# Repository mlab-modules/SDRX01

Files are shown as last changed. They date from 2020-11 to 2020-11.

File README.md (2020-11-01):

<!--- module --->
# SDRX01B - SDR Receiver
<!--- Emodule --->

<!--- subtitle --->
A improved design of well known DR2G software defined receiver. It is capable to work from almost zero frequencies up to 200MHz but up to 450MHz with selected parts.
<!--- Esubtitle --->

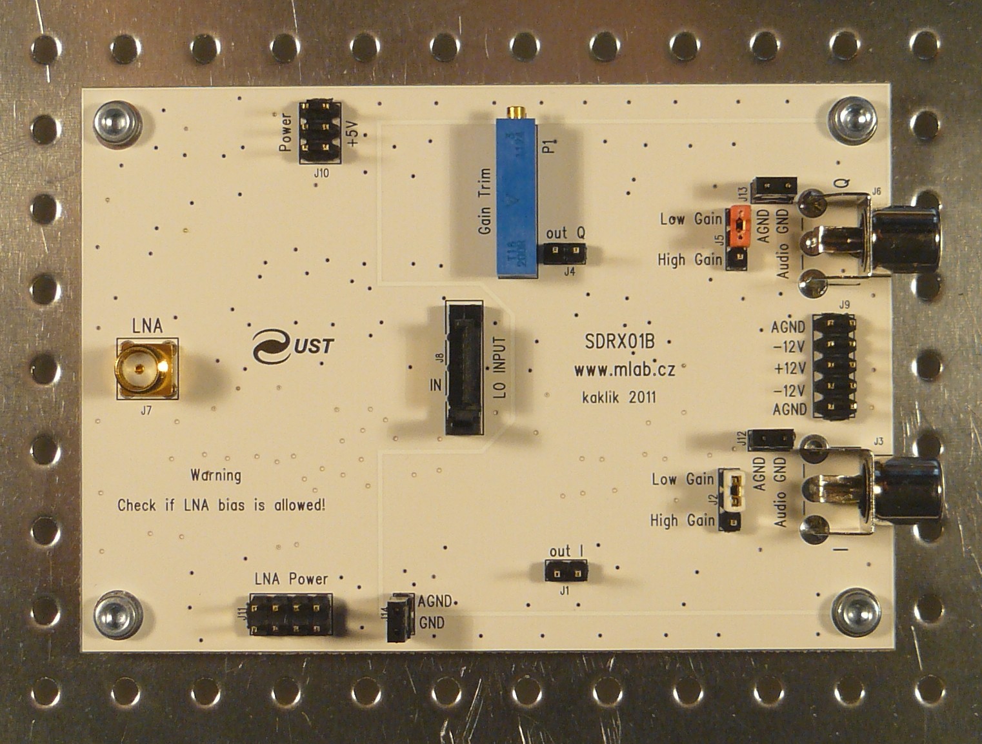
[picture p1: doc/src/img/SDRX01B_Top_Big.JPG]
SDRX01B Top


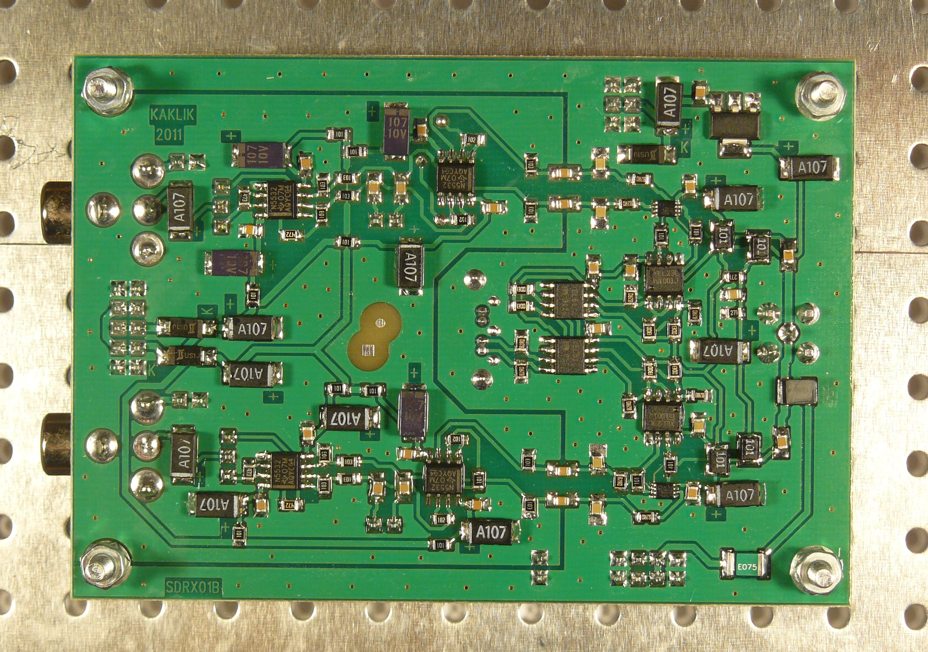
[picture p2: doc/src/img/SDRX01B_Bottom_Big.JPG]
SDRX01B Bottom


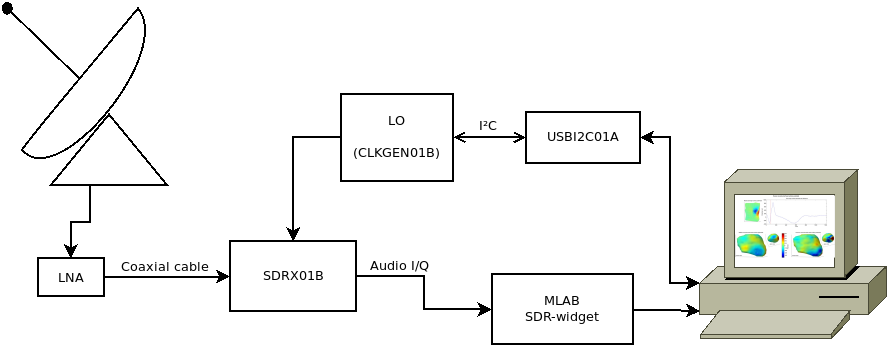
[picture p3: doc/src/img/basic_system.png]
SDRX01B Basic usage


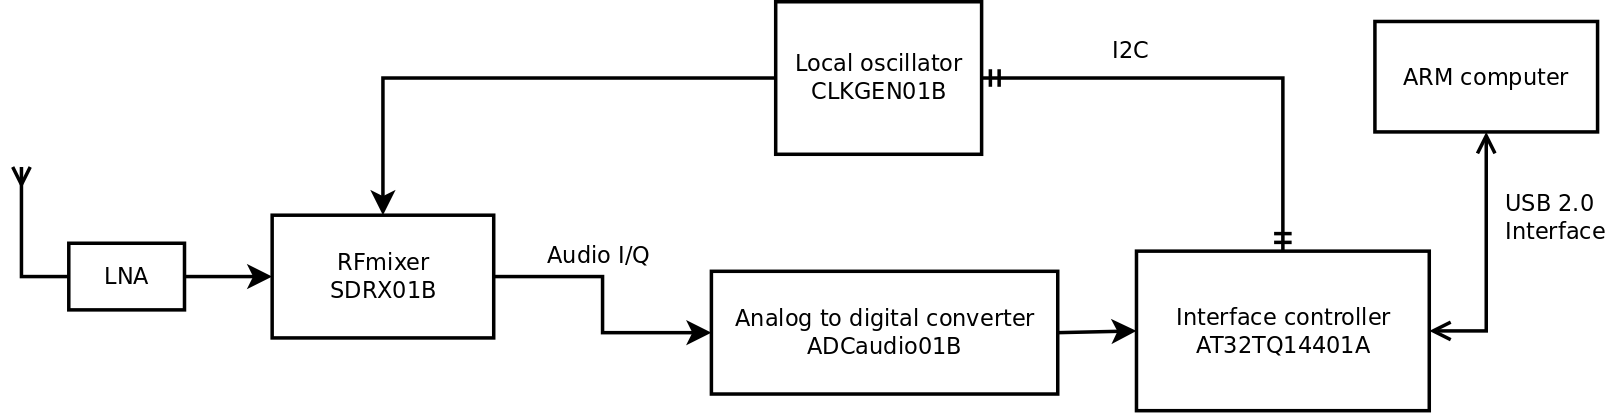
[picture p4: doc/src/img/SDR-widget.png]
Sdr-widget


<!--- description --->

<!--- Edescription --->

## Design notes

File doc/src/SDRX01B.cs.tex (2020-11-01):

\documentclass[12pt,a4paper,oneside]{article}
\usepackage[colorlinks=true,unicode]{hyperref}
\usepackage[utf8]{inputenc}
\usepackage[czech]{babel}
\usepackage{graphicx}
\usepackage{pdfpages}
\textwidth 16cm \textheight 25cm
\topmargin -1.3cm 
\oddsidemargin 0cm
\usepackage{footnote}
\pagestyle{empty}
\begin{document}
\title{Softwarově definovaný přijímač SDRX01B nejen pro radioastronomii}
\author{Jakub Kákona, kaklik@mlab.cz }
\maketitle

\begin{abstract}
Cílem této konstrukce je vytvořit dostupný softwarově definovaný přijímač pro použití v radioastronomii. A nahradit tak původní čistě analogové konstrukce, jako RadioJOVE a další. Díky dosaženým parametrům je ale dobře použitelný i v jiných aplikacích, jako například přehledový přijímač pro radioamatéry nebo jako studijní pomůcka pro výuku VF techniky. 
\end{abstract}

\begin{figure} [htbp]
\begin{center}
\includegraphics [width=80mm] {./img/SDRX01B_Top_Big.JPG} 
\end{center}
\end{figure}

\begin{figure} [b]
\includegraphics [width=25mm] {./img/SDRX01B_QRcode.png} 
\end{figure}

\newpage
\tableofcontents

\section{Technické parametry}
\begin{savenotes}
\begin{table}[htbp]
\begin{center}
\begin{tabular}{|c|c|p{5cm}|}
\hline
Parametr & Hodnota & \multicolumn{1}{|c|}{Poznámka} \\
\hline
Napájecí napětí analogové části & $\pm$12V \footnote{první kusy vyrobené do 1.8.2011 ale mohou mít osazené pouze 10V konenzátory 100uF} 100mA &  Typicky 30mA \\ \hline
Napájecí napětí digitální části & +5V &  300mA \\ \hline
Napájecí napětí LNA & do +20V &  max 500mA \\ \hline
Přijímaný frekvenční rozsah  & 0,5 - 200 MHz\footnote{Prakticky je omezen kvalitou vstupních spínačů směšovače} &  \\ \hline
Vstupní frekvenční rozsah LO  & 1 - 400 MHz \footnote{Digitální část je dimenzována do cca 1 GHz} & Limitem je LO  \\ \hline
IIP3  & $>$ 0 dB & Hodnota závisí na parametrech zvukové karty \\ \hline
MDS  & -120 dBm @ 1kHz BW & -117 dBm pro 3 dB nad šumem  \\ \hline
Potlačení zrcadlového příjmu   & $>$ 50 dB & Typicky 70dB \footnote{Hodnota závisí na přesnosti nastavení P1}\\ \hline
Zisk & 40-60dB & Lze částečně ovlivnit konfigurací NF zesílení\\ \hline
Šumové číslo  & $<$ 30dB & \\ \hline
\end{tabular}
\caption{Údaje uvedené v tabulce jsou platné pro příjem na frekvenci 150MHz.}
\label{Technicke_parametry}
\end{center}
\end{table}
\end{savenotes}

\newpage
\section{Popis konstrukce}

\subsection{Zapojení}
Zapojení přijímače vychází z původní konstrukce SDR přijímače DR2G \cite{DR2G}  který požívá CMOS součástky. Nyní je u přijímače změněný hlavně obvod vstupu pro lokální oscilátor a umožňuje tak používat přijímač na vyšších kmitočtech, neboť nedělí vstupní frekvenci 4mi, jako původní konstrukce ale pouze 2mi. To mimo jiné znamená, že nejvyšší pracovní kmitočet již není limitován vstupní logikou, ale analogovými spínači a v menší míře i převodníky LVPECL-CMOS těsně před spínači. Použitá diferenciální LVPECL logika navíc také umožňuje podstatně snížit vyzařování. Dále byly vyměněny analogové spínače ve směšovači. Ty nyní spínají trochu rychleji, ale hlavně mají lepší izolační parametry, což umožňuje lepší odstup signálu od šumu.

\includepdf[pages={1,2,3,4},landscape=true]{../../SCH/sdrx.pdf}

Další nezbytnou součástí přijímače je lokální oscilátor, který se připojuje k přijímači externě pomocí krátkého SATA kabelu. Jako LO lze použít modul CLKGEN01B osazený 570ABB000107DG. SATA kabel je vhodné volit co nejkratší kvůli minimalizaci zemní smyčky a vyzařování.

\subsection{Odrušení}
Pro správnou funkci přijímače je nutné řádné odrušení napájecích zdrojů. Vhodné je také omezit zemní smyčky a zem rozvádět pokud možno hvězdicově. Konstrukce obsahuje několik Jumperů, kterými je možné různými způsoby propojit země a eliminovat tak proudy tekoucí mezi nimi. Zvláště nežádoucí je proměnný proud tekoucí stíněním, například u výstupních CINCHů, Jumpery proto umožňují jejich odpojení od AGND přijímače. V tom případě se ale předpokládá propojení země ADC a AGND externím vedením, tak aby jím tekoucí proud neindukoval signál v analogových obvodech.
V některých případech (anténa uzemněna na hromosvod, nebo daleko od přijímače) se může vyskytnout problém se síťovým napájeným 50Hz indukovaným do svodu antény. Ten pak vytváří okolo nulové frekvence spektrogramu nežádoucí hrb, ten lze pak v takovém případě eliminovat oddělovacím transformátorem, na vstupu přijímače.     

Při provozu je také vhodné zabezpečit dostatečný útlum zpětně vyzařovaného útlumu ze směšovače, který by mohl rušit jiná zařízení a spoje. Na vstupu přijímače proto musí být zařazen izolační prvek, jako například LNA. 

\subsection{Mechanická konstrukce}

Mechanická konstrukce je řešena na dvouvrstvé desce s geometrií kompatibilní se základo\-vou deskou MLAB (Pro lepší odstínění přijímače je vhodné použít duralovou desku ALBASE). Dvouvrstvý plošný spoj je zvolen hlavně kvůli kvalitnímu odstínění okolního rušení horní měděnou vrstvou. To umožňuje přijímače instalovat i velmi blízko sebe případně i nad sebe avšak všechny konektory  kromě NF audio výstupu předpokládají přivedení kabelu kolmo na rovinu desky. SMA konektor je možné osadit i úhlový s přivede\-ním kabelu do boku, ale za cenu nepatrně vyššího útlumu úhlového konektoru. Při těsné montáži je potřeba počítat i s určitou teplotní stabilizací, neboť digitální část okolo spínaného směšovače má poměrně velký příkon a způsobuje zahřívání zhruba o 15$^\circ C$ nad okolní teplotu. Pokud je od přijímače vyžadována dlouhodobá stabilita je proto vhodné jej umístit do termostatovaného boxu společně s LO.

\section{Výroba}
Výrobu vlastní desky pro přijímač nemohu doporučit. Neboť domácí výroba je dvouvrstvého plošného spoje je náročná sama o sobě a tento motiv plošného spoje navíc obsahuje plošky pro komponenty s poměrně vysokou třídou přesnosti.

\subsection{Osazení}
Vlastní osazení přijímače předpokládá zvládnutí SMT technologie. Nejkomplikovanější část je letování analogových spínačů u kterých je nutné dát pozor na přehřátí a je tedy vhodné použít více tavidla. Následně je potřeba pod mikroskopem zkontrolovat kvalitu pájení (zkraty, nepřipojené nožičky).

\begin{figure} [h!tbp]
  \centering
  
  
  \caption{Osazovací plán horní a spodní strany plošného spoje}
  \label{fig:osazovaci_plan}
\end{figure}

\begin{table}[h!]
\begin{center}
\begin{tabular}{ |c|p{5cm}|c|c| }
\hline 
Počet & Označení & Typ  & Pouzdro  \\ 
\hline 
18	&	C1, C4, C8, C10, C12, C15, C19, C21, C23, C27, C30, C32, C36, C39, C40, C41, C42, C45	&	100nF	&	805	\\
17	&	C2, C5, C9, C11, C13, C16, C20, C22, C24, C31, C35, C43, C44, C46, C47, C48, C49	&	47uF	&	SMC	\\
4	&	C3, C6, C14, C17	&	4,7uF	&	805	\\
4	&	C25, C28, C33, C37	&	470nF	&	805	\\
4	&	C26, C29, C34, C38	&	22nF	&	805	\\
3	&	D1, D2, D3	&	M4	&	SMA	\\
1	&	F1	&	750mA	&		\\
5	&	J1, J4, J12, J13, J14	&	JUMP2	&		\\
2	&	J2,J5	&	JUMP3	&		\\
1	&	J3	&	CINCH I	&		\\
1	&	J6	&	CINCH Q	&		\\
1	&	J7	&	SMA6251A13G50	&		\\
1	&	J8	&	JUMP7	&		\\
1	&	J9	&	JUMP2X5	&		\\
1	&	J10	&	JUMP2X3	&		\\
1	&	J11	&	JUMP2X4	&		\\
5	&	L1, L2, L3, L4, L5	&	100uH	&		\\
1	&	P1	&	200	&	805	\\
13	&	R1, R2, R8, R14, R15, R16, R17, R28, R30, R32, R34, R36, R40	&	100	&	805	\\
12	&	R3, R5, R7, R9, R12, R13, R18, R19, R23, R24, R27, R29	&	10k 1\%	&	805	\\
4	&	R4,R11,R21,R26	&	1k 1\%	&	805	\\
2	&	R6,R22	&	47k 1\%	&	805	\\
2	&	R10,R25	&	4k7 1\%	&	805	\\
10	&	R31, R33, R35, R39, R45, R46, R47, R48, R51, R52	&	82	&	805	\\
2	&	R37,R38	&	330	&	805	\\
6	&	R41,R42,R43,R44,R49,R50	&	130	&	805	\\
2	&	U1,U3	&	LT6231	&	SO8	\\
2	&	U2,U4	&	NE5532	&	SO8	\\
2	&	U5,U6	&	NC7WB66	&		\\
2	&	U7,U9	&	MC100EP51	&	SO8	\\
2	&	U8,U10	&	SY100ELT23	&	SO8	\\
1	&	U11	&	LM1117MPX	&	SOT	\\
\hline 
\end{tabular}
\end{center}
\caption{Seznam součástek plošného spoje.}
\label{seznam_soucastek}
\end{table}

\subsection{Testování}
Testování přijímače spočívá v připojení na zdroje napájecího napětí s omezením proudu nastaveným na maximální hodnoty uvedené v tabulce \ref{Technicke_parametry}. Symetrický napájecí zdroj musí být dostatečně kvalitní a vyhlazený, aby nedocházelo k průniku rušení do analogové části. Je taktéž vhodné aby i symetrický zdroj měl proudové omezení. Pokud proudový odběr nepřekračuje stanovené limity. Můžeme připojit i lokální oscilátor. Pro testovací účely stačí použít modul CLKGEN01B pouze s připojeným napájením, tím dosáhneme přivedení jeho základní frekvence 10 MHz na vstupní děličku přijímače.  

Nyní můžeme osciloskopem zkontrolovat signál na vstupu analogových spínačů, kde by po připojení oscilátoru přes SATA kabel měl být měřitelný TTL signál. Se střídou 50 \% a frekvencí 5 MHz. Je potřeba změřit každý vstup spínače samostatně.  Pokud jsou analogové spínače v pořádku, lze pokračovat v ověření parametrů analogové části. To provedeme změřením napěťového offsetu na výstupním operačním zesilovači. Jeho hodnota by neměla být více než 1 V, měření je vhodné provádět osciloskopem, neboť tím lze detekovat i případné kmitání operačních zesilovačů. 

\subsection{Nastavení}

Následně je důležité nastavení shodných amplitud obou výstupních kanálů I a Q na stejnou hodnotu pomocí víceotáčkového trimru na horní straně desky. To lze udělat buď pomocí zvukové karty a minimalizace zrcadlových kmitočtů nějakého relativně silného AM vysílače. Nebo lze použít i metodu, kdy pomocí Jumperů, které slouží na výběr zesílení odpojíme jeden kanál (ten ve větvi s trimrem) a v softwaru si označíme aktuální úroveň signálu z antény. Pak analogicky kanál odpojíme připojíme naopak původně odpojený. Pomocí trimru pak nastavíme stejnou hodnotu signálu. Tento způsob je velmi jednoduchý a lze ho použít i za chodu, ale není příliš přesný. hodí se spíše na detekci poruchy (nefungující jeden z kanálů). 

Nejpřesnější metoda je použití signálového generátoru, který necháme vysílat do přijí\-ma\-če signálem cca -50dBm na požadovaném kmitočtu, kde potřebujeme přijímač zkalibrovat a trimrem nastavíme zrcadlový kmitočet ve spektrogramu na minimální hodnotu. Pokud nemáme signálový generátor lze využít například další přijímač SDRX01B s dalším lokálním oscilátorem. Který díky zpětnému vyzařování do antény umožní stejný postup.
Další jeměšjí potlačení zrcadlového kmitočtu lze provádět vhodným nastavením zesílení jednotlivých kanálů ADC a jejich fázovým posuvem. Většina programů pro SDR má proto možnost vyvážení amplitudy a fáze.  

\section{Programové vybavení}

Základním programovým vybavením jsou všechny softwary využívající zvukovou kartu v komplexním režimu (I/Q) pro vstup signálu. Tedy například programy jako Winrad, WinradHD, HDSDR či Spectrum Lab. Do kterých většinou stačí přidat knihovnu pro ovládání LO s Si570, nebo lokální oscilátor ovládat jiným softwarem.

\section{Důležité poznámky k používání}
\begin{itemize}
\item Vzhledem k použitému principu spínaného směšovače přijímač z principu poměrně silně vyzařuje zpět do antény. \textbf{Nesmí se proto využívat k poslechu chráněných pásem přímo bez izolačního členu na vstupu!} (izolačním členem je myšlen prvek, který zabezpečí dostatečný útlum signálu směřujícího do antény, obvykle jde o LNA, nebo izolační zesilovač)

\item Aktuální způsoby použití a poznatky uživatelů přijímače najdete na wiki stránce MLAB \cite{SDRX}.
\end{itemize}

\begin{thebibliography}{99}
\bibitem{DR2G}{Původní konstrukce přijímače DR2G} 
\href{http://yu1lm.qrpradio.com/SMT SDR RX DR2G-YU1LM.pdf}{http://yu1lm.qrpradio.com/SMT SDR RX DR2G-YU1LM.pdf}
\bibitem{SDRX}{MLAB wiki stránka přijímače SDRX01B} 
\href{http://wiki.mlab.cz/doku.php?id=cs:sdrx}{http://wiki.mlab.cz/doku.php?id=cs:sdrx}
\end{thebibliography}
\end{document}

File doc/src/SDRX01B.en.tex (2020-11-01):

\documentclass[12pt,a4paper,oneside]{article}
\usepackage[colorlinks=true]{hyperref}
\usepackage[utf8]{inputenc}
\usepackage[english]{babel}
\usepackage{graphicx}
\usepackage{pdfpages}
\textwidth 16cm \textheight 25cm
\topmargin -1.3cm 
\oddsidemargin 0cm
\usepackage{footnote}
\pagestyle{empty}
\begin{document}
\title{Software Defined Receiver SDRX01B not only for radioastronomy}
\author{Jakub Kákona, kaklik@mlab.cz }
\maketitle

\begin{abstract}
This paper describe a design of Software Defined Receiver suitable for radioastronomy purposes. The receiver which has been developed in this project replacing old analog constructions such as RadioJOVE and others.
\end{abstract}

\begin{figure} [htbp]
\begin{center}
\includegraphics [width=80mm] {./img/SDRX01B_Top_Big.JPG} 
\end{center}
\end{figure}

\begin{figure} [b]
\includegraphics [width=25mm] {./img/SDRX01B_QRcode.png} 
\end{figure}

\newpage
\tableofcontents

\section{Technical parameters}
\begin{savenotes}
\begin{table}[htbp]
\begin{center}
\begin{tabular}{|c|c|p{5cm}|}
\hline
\multicolumn{1}{|c|}{Parameter} & \multicolumn{1}{|c|}{Value} & \multicolumn{1}{|c|}{Note} \\ \hline
Power voltage for analog circuits & $\pm$12 V 100mA \footnote{First devices manufactured before 1.8.2011 may be equipped by 10 V tatal capacitors onl thus cannot by longly stressed by $\pm$12 V power voltage } &  Typical current draw 30 mA \\ \hline
Powering voltage for digital part & +5V &  300mA \\ \hline
Bias of optional LNA & up to +20V max 500mA &   Fused by 750mA on board \\ \hline
Frequency range  & 0,5 - 200 MHz & With populating by chosen parts even up 450MHz \\ \hline
IIP3  & $>$ 0dB & Preliminary \\ \hline
Gain & 40-60dB & Selectable by jumper \\ \hline
Self noise number & $<$ 30dB & \\ \hline
\end{tabular}
\end{center}
\end{table}
\end{savenotes}

\newpage
\section{Description of construction}

\subsection{Circuit}
Construction  of the receiver is delivered from the DR2G receiver \cite{DR2G} which uses CMOS components completely. The main change in this construction is a local oscillator input circuit which allow to receiver work at higher frequencies, because this construction do not divide the input frequency by 4, such as original construction but only by 2. In addition there was be replaced switches in the sampling mixer by faster type and board layout was optimized for higher frequencies and better noise rejection.

\includepdf[pages={1,2,3,4},landscape=true]{../../SCH/sdrx.pdf}

The necessary part of the receiver is a Local Oscillator (LO), which must be connected to receiver via SATA cable. The LO may be a CLKGEN01B module populated by the 570ABB000107DG chip. SATA cable should be as short as possible to minimize ground loops.

\includepdf[pages={1},landscape=true]{../../CAM_DOC/O1.pdf}

\includepdf[pages={1},landscape=true]{../../CAM_DOC/O2.pdf}

\subsection{EMI suppression}
For proper function of receiver is necessary to use proper low noise symmetric power supply (classical PC power supply is unacceptable). There is need for proper routing of grounding wires, which must be routed in star topology. In addition there is few jumpers on the board of receiver to allow proper selection of ground connection.

\subsection{Mechanical construction}

The mechanical construction of the receiver resulted (For better EMI suppression is suggested use of metal MLAB base such as ALBASE). Two layer PCB is chosen mainly because of better shielding by top cooper layer and even because better grounding. In case where long term stability is required receiver must be inserted to thermostatic box together with LO. 

\subsubsection{Setting}
There is one easy step for proper setting of the receiver. The trimmer P1 must be tunned to value where the strength of mirror frequencies is minimized or zero. This can be achieved by tunning the receiver to some strength AM transmitter and slowly turning by P1 until the mirror of signal in frequency spectrum is minimized. 

\section{Software tools}

The basic software tools for this receiver are all programs designed to work with sound card as I/Q input. Such as Winrad, WinradHD or Spectrum Lab. There is usually request to add a LO library for tunning Si570, but tunning the LO by separate software is acceptable too.

\begin{thebibliography}{99}
\bibitem{DR2G}{The original construction of DR2G} 
\href{http://yu1lm.qrpradio.com/SMT SDR RX DR2G-YU1LM.pdf}{http://yu1lm.qrpradio.com/SMT SDR RX DR2G-YU1LM.pdf}

\end{thebibliography}
\end{document}

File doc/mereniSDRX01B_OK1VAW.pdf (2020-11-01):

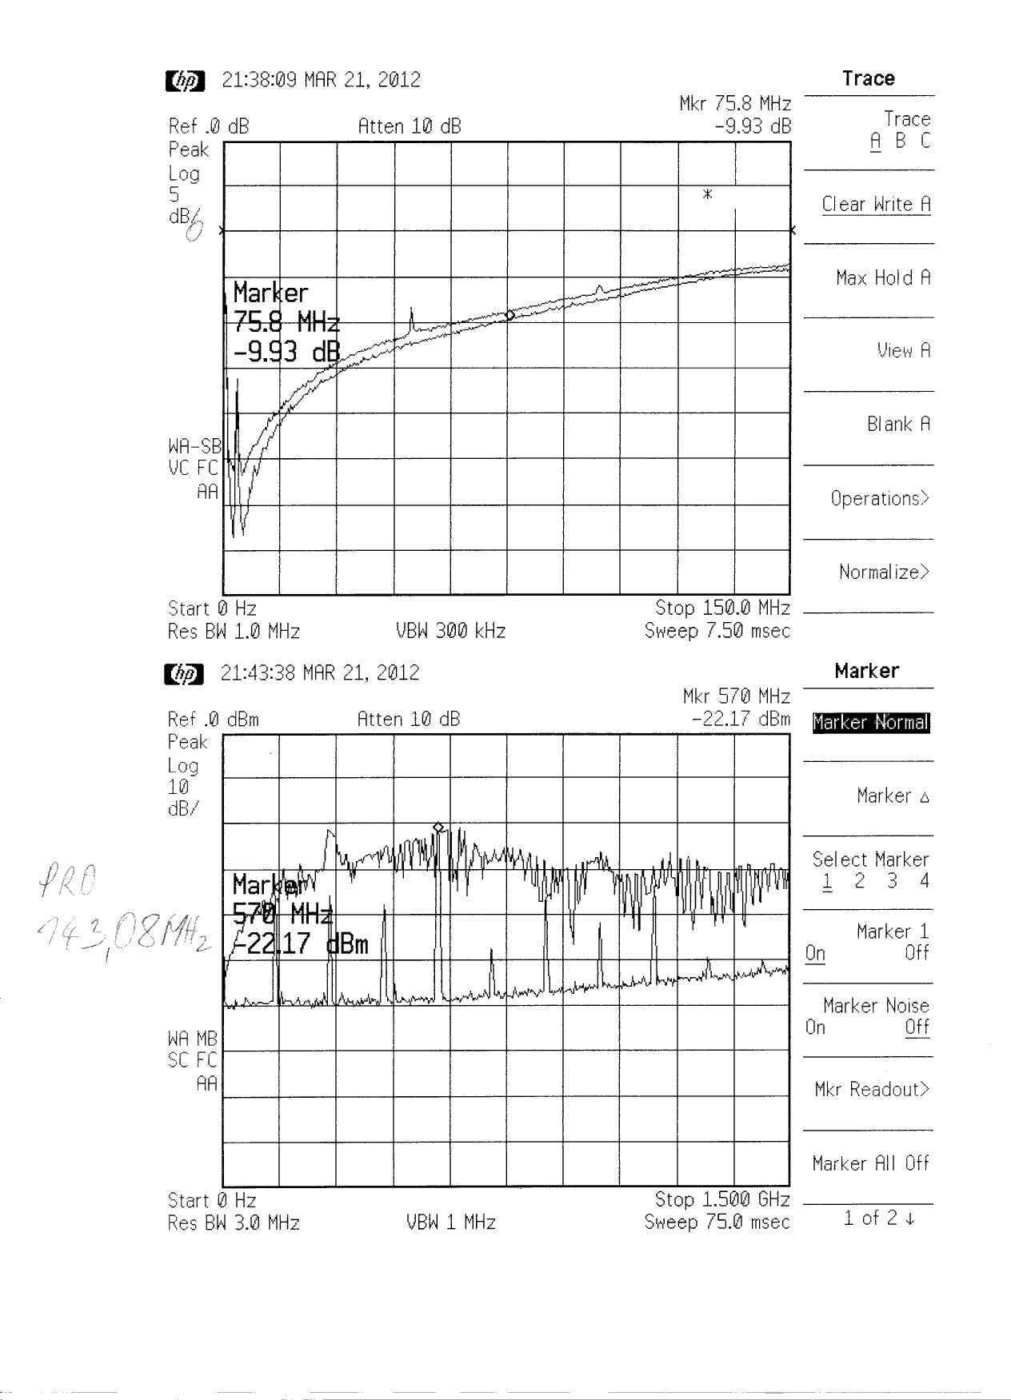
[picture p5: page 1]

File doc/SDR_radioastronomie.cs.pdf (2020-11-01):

## SDR Radiostronomie

Možnost astronomického
pozorování pro den i noc
nezávisle na počasí i uprostřed města.

## Základní pozorovatelné objekty

- Ionosféra
- Sluneční bouře
- Meteory
- Magnetické bouře Jupiteru
- Galaktický šum

## Potřebné vybavení

Anténa, zesilovač, přijímač, zvuková karta a počítač.

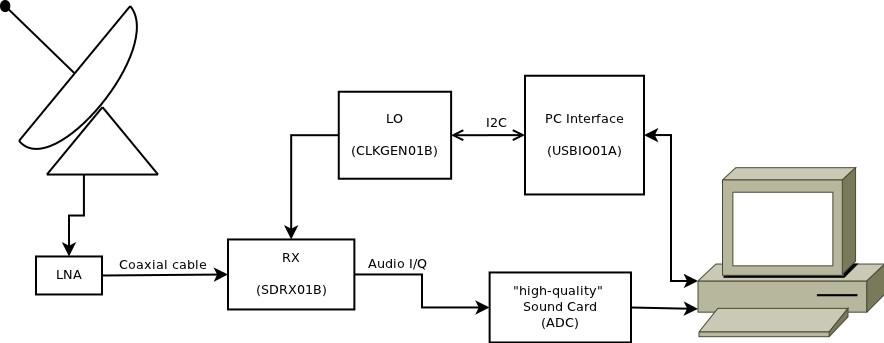
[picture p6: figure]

## Příklad - Detekce meteorů

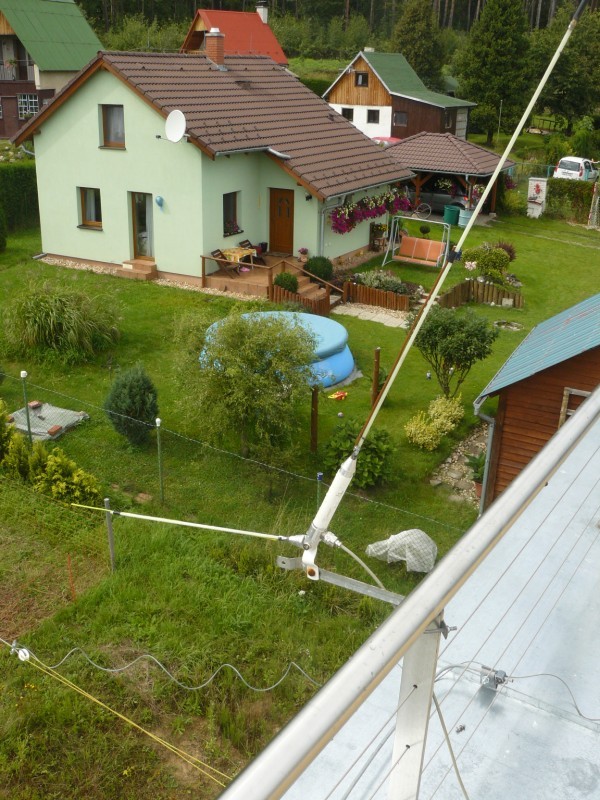
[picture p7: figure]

„balkónová anténa“
- ¼ λ Vertical (Ground
Plane)
- Předzesilovač
LNA01A
- Přijímač SDRX01B

## Pozorovací pracoviště

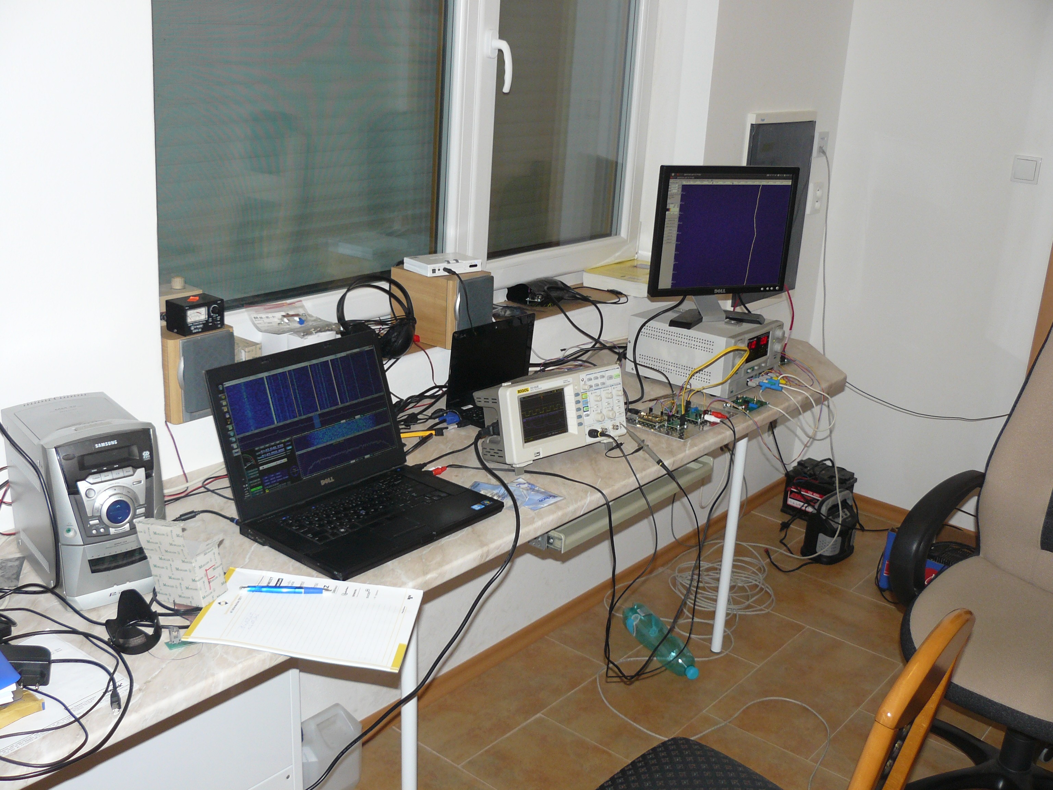
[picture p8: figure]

## Výsledky (Drakonidy)

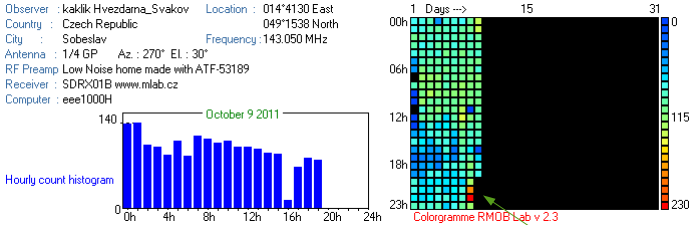
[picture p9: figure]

Detekováno krátké maximum

## Spektrogramy z maxima

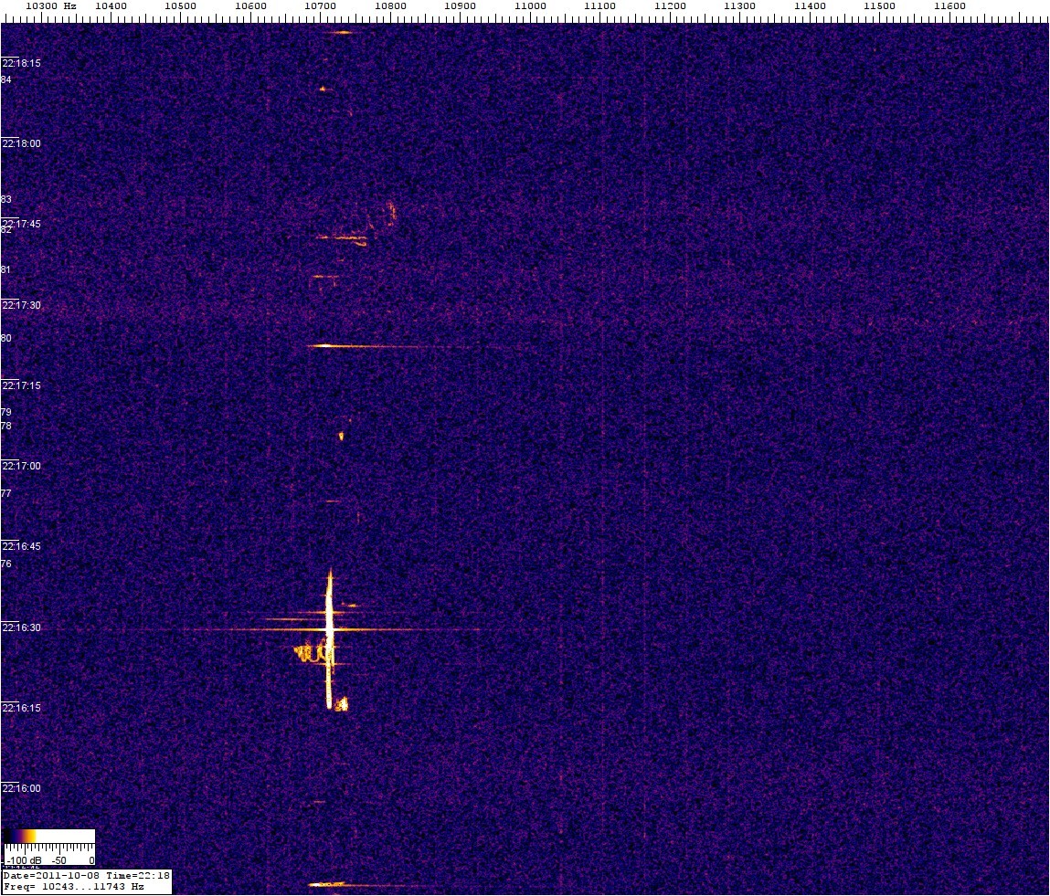
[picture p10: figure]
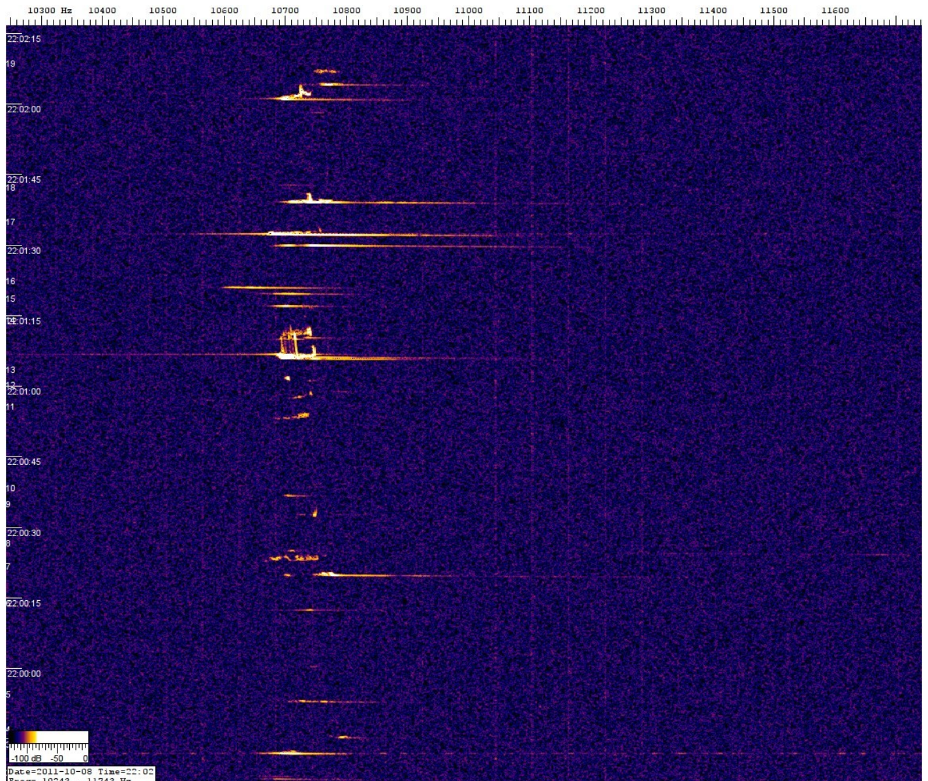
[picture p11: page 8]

## Budoucí vývoj

- Časově synchronizovaný více staniční systém

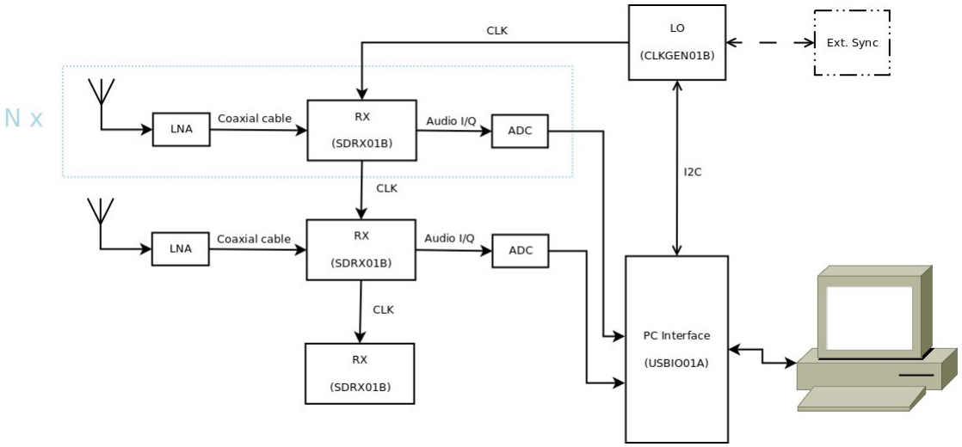
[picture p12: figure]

Spojení více základních sestav do většího celku

•Eliminace lokálního rušení

•Detekce i velmi slabých objektů (pulzary, supernovy, galaxie)

•Zvětšení rozlišení (Není tolik omezeno vlivem atmosféry)

•Výpočet dalších parametrů (dráha meteoritu)

## Pořizovací náklady

Základní sestava
- Kmitočtový syntezátor
2000Kč
- Přijímač SDRX01B
1700Kč
- Nízkošumový
zesilovač ~450Kč

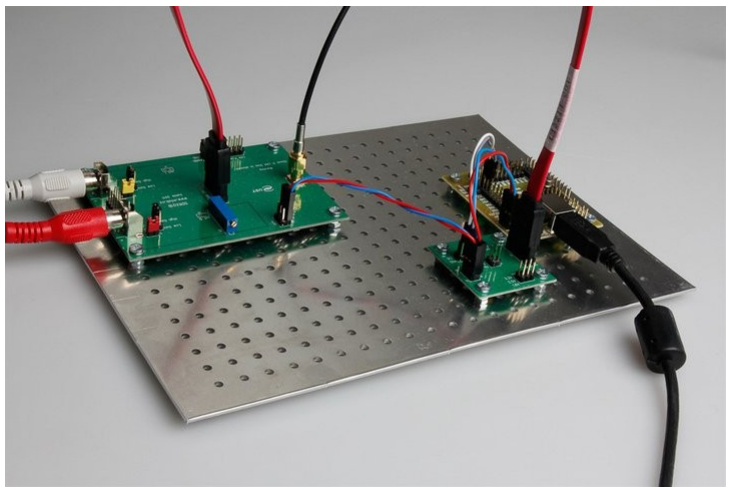
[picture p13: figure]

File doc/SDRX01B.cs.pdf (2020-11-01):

# Softwarově definovaný přijímač SDRX01B nejen pro radioastronomii

### Jakub Kákona, kaklik@mlab.cz

### 25. srpna 2016

Abstrakt

Cílem této konstrukce je vytvořit dostupný softwarově definovaný přijímač pro použití v radioastronomii. A nahradit tak původní čistě analogové konstrukce, jako RadioJOVE a další. Díky dosaženým parametrům je ale dobře použitelný i v jiných aplikacích, jako například přehledový přijímač pro radioamatéry nebo jako studijní pomůcka pro výuku VF techniky.


## Obsah

1 Technické parametry | 2
2 Popis konstrukce | 3
3 Výroba | 8
4 Programové vybavení | 11
5 Důležité poznámky k používání | 11

## 1 Technické parametry

Parametr | Hodnota | Poznámka
Napájecí napětí analogové části | ±12V 1 100mA | Typicky 30mA
Napájecí napětí digitální části | +5V | 300mA
Napájecí napětí LNA | do +20V | max 500mA
Přijímaný frekvenční rozsah | 0,5 - 200 MHz²
Vstupní frekvenční rozsah LO | 1 - 400 MHz 3 | Limitem je LO
IIP3 | > 0 dB | Hodnota závisí na paramet-rech zvukové karty
MDS | -120 dBm @ 1kHz BW | -117 dBm pro 3 dB nad šumem
Potlačení zrcadlového příjmu | > 50 dB | Typicky 70dB 4
Zisk | 40-60dB | Lze částečně ovlivnit konfi-gurací NF zesílení
Sumové číslo ˇ | < 30dB

Tabulka 1: Udaje uvedené v tabulce jsou platné pro příjem na frekvenci 150MHz. ´

1první kusy vyrobené do 1.8.2011 ale mohou mít osazené pouze 10V konenzátory 100uF 2Prakticky je omezen kvalitou vstupních spínačů směšovače
3Digitální část je dimenzována do cca 1 GHz
4Hodnota závisí na přesnosti nastavení P1

## 2 Popis konstrukce

### 2.1 Zapojení

Zapojení přijímače vychází z původní konstrukce SDR přijímače DR2G [1] který požívá CMOS součástky. Nyní je u přijímače změněný hlavně obvod vstupu pro lokální oscilátor a umožňuje tak používat přijímač na vyšších kmitočtech, nebot’ nedělí vstupní frekvenci 4mi, jako původní konstrukce ale pouze 2mi. To mimo jiné znamená, že nejvyšší pracovní kmitočet již není limitován vstupní logikou, ale analogovými spínači a v menší míře i převodníky LVPECL-CMOS těsně před spínači. Použitá diferenciální LVPECL logika navíc také umožňuje podstatně snížit vyzařování. Dále byly vyměněny analogové spínače ve směšovači. Ty nyní spínají trochu rychleji, ale hlavně mají lepší izolační parametry, což umožňuje lepší odstup signálu od šumu.

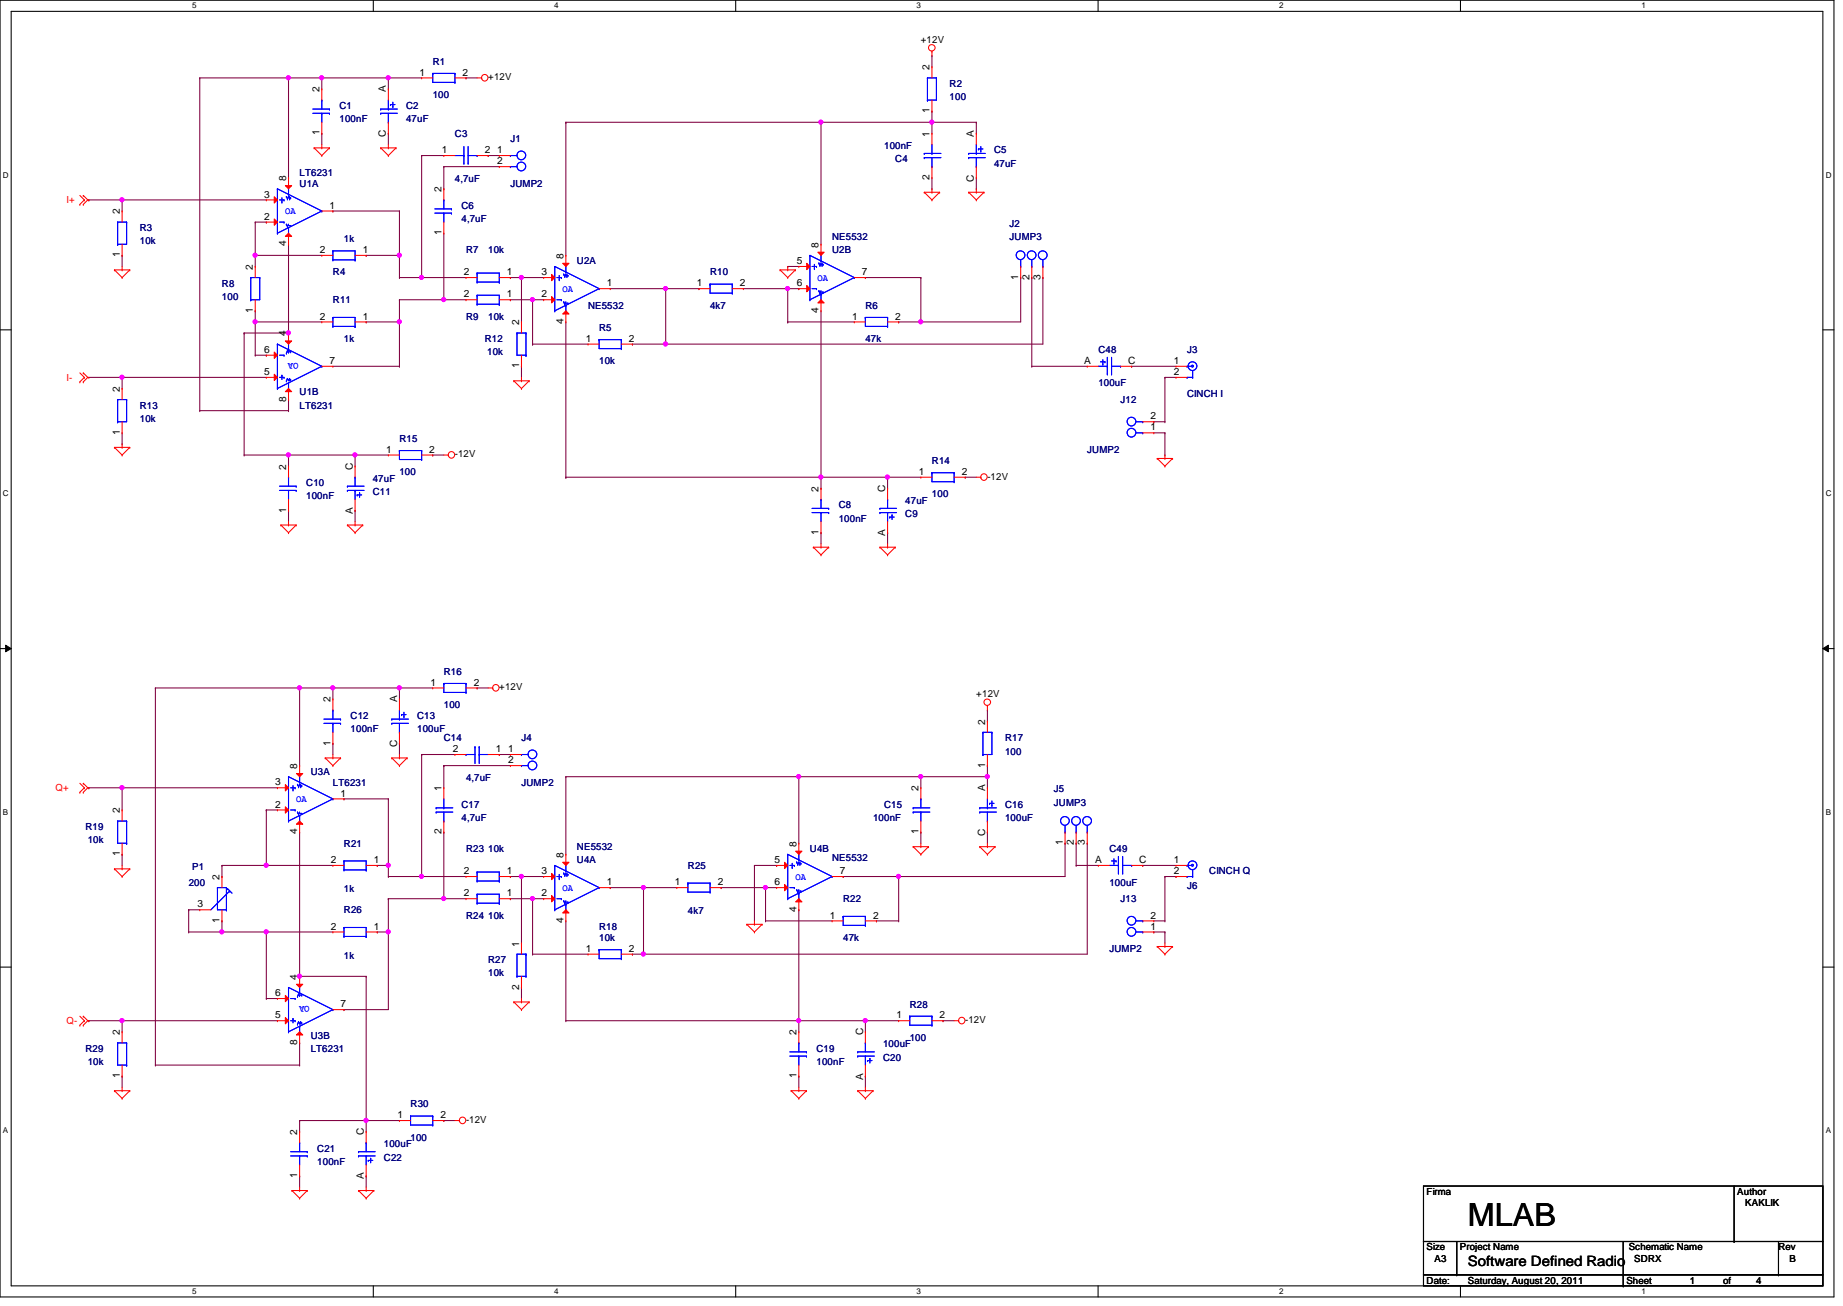
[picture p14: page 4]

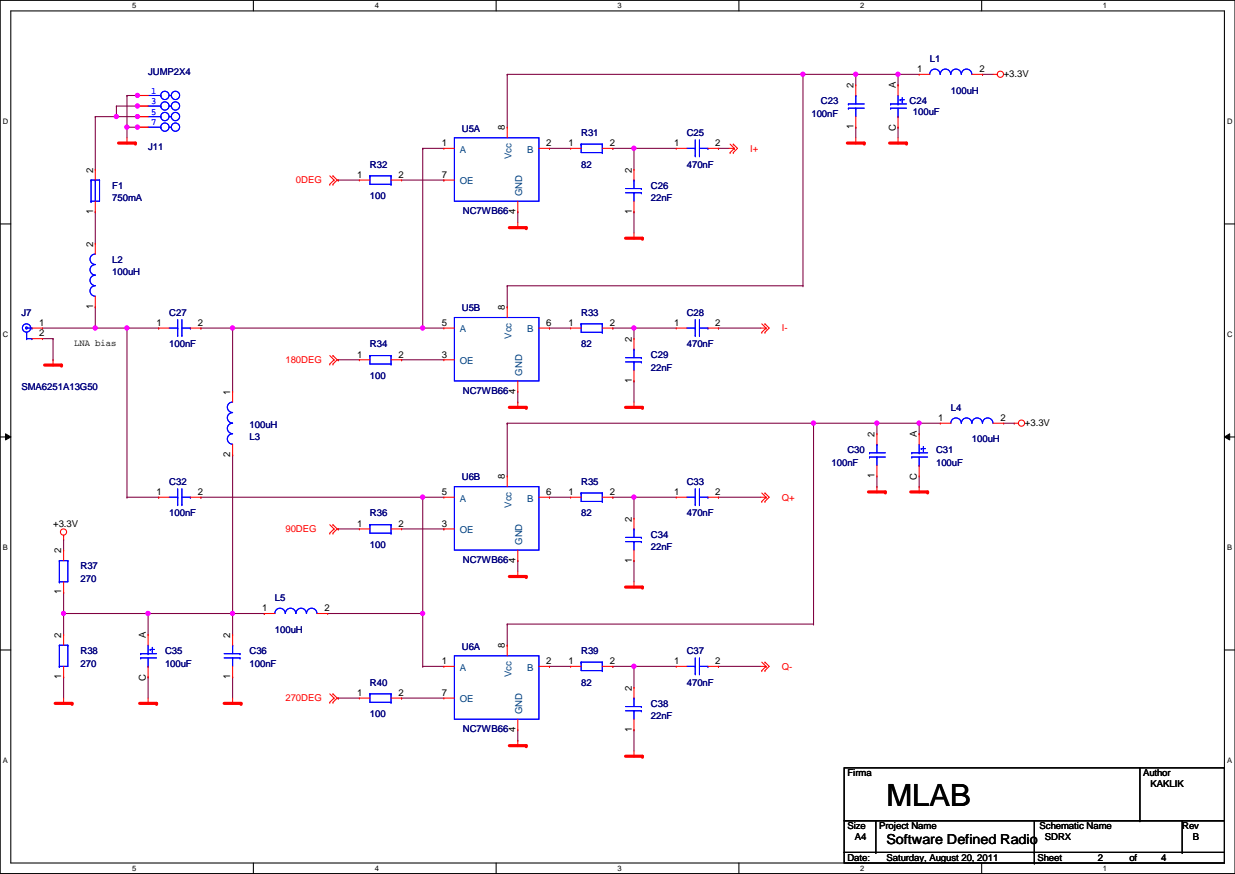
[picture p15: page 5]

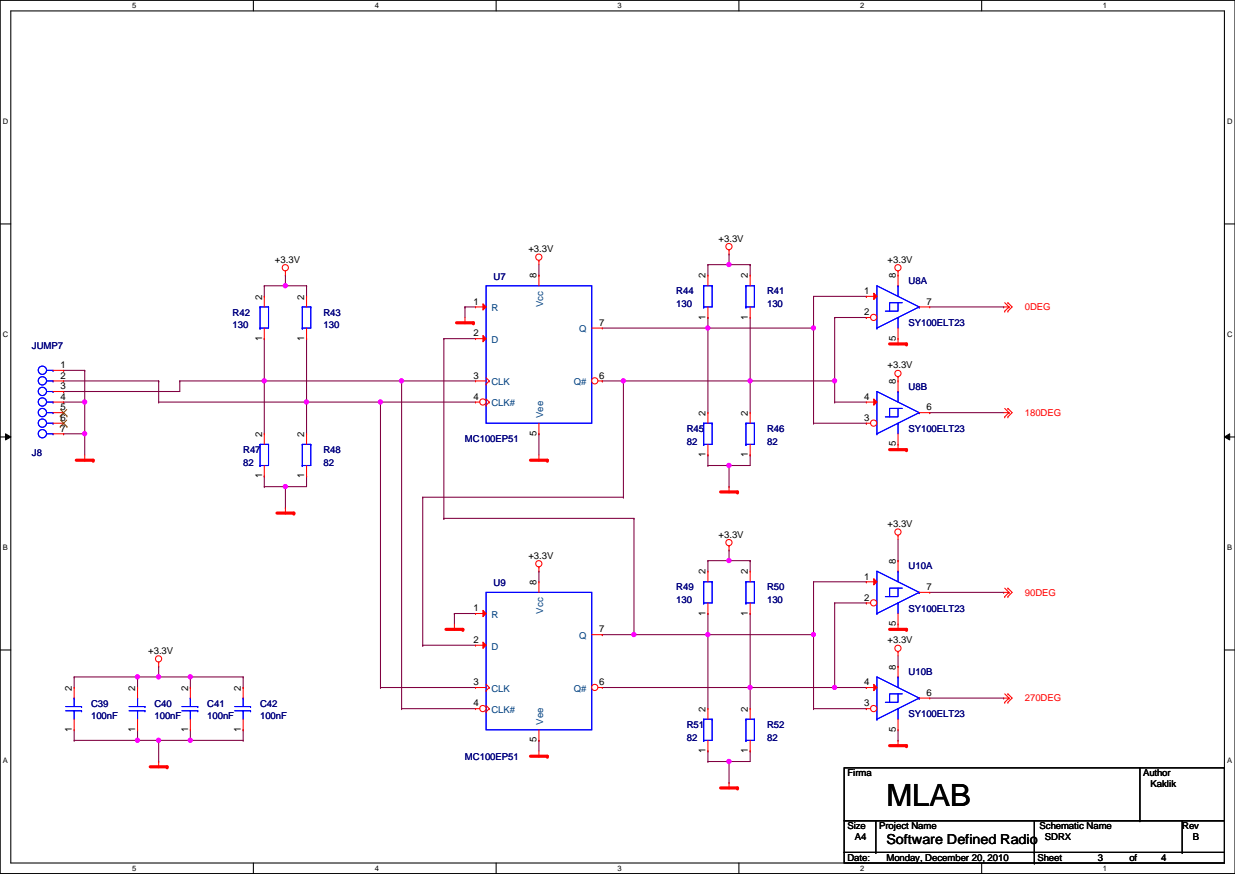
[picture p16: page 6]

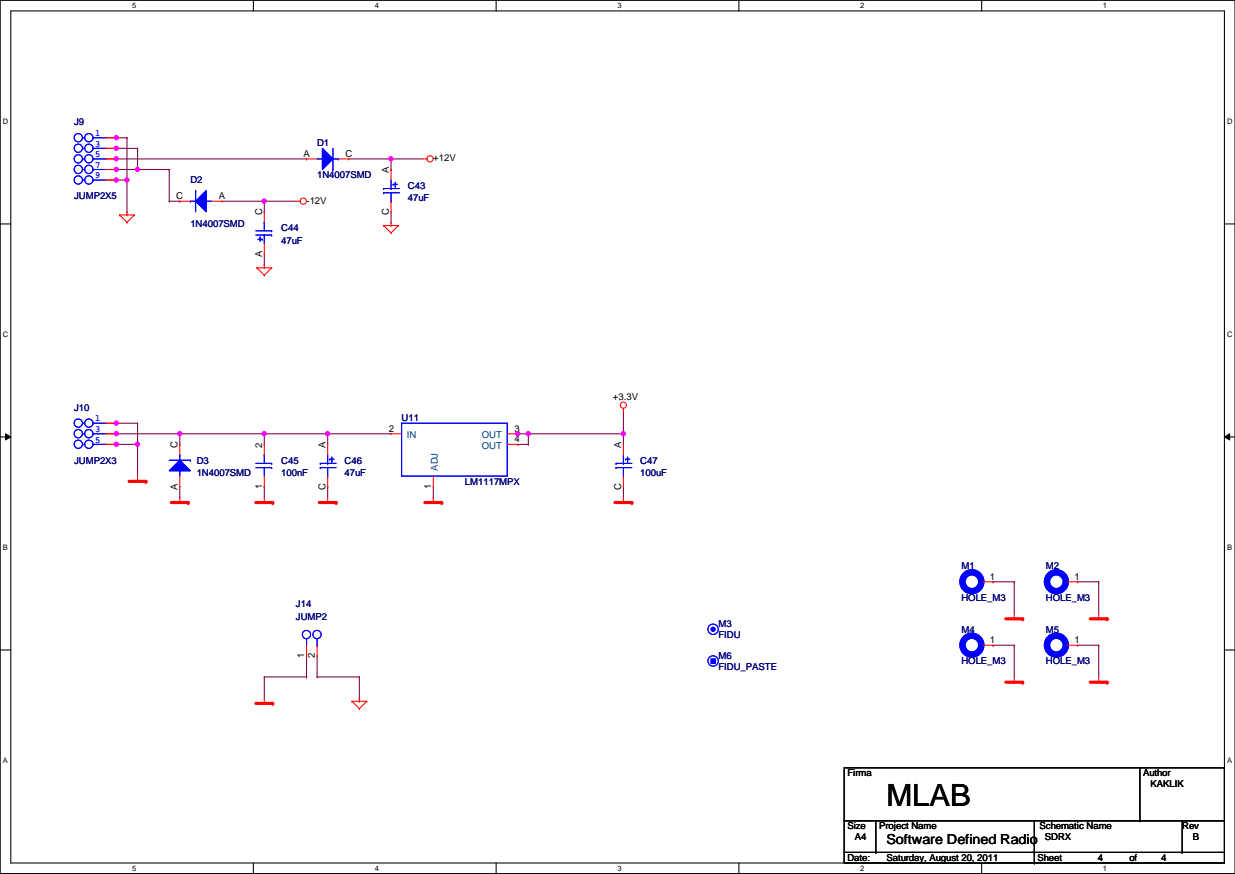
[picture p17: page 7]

Další nezbytnou součástí přijímače je lokální oscilátor, který se připojuje k přijímači externě pomocí krátkého SATA kabelu. Jako LO lze použít modul CLKGEN01B osazený 570ABB000107DG. SATA kabel je vhodné volit co nejkratší kvůli minimalizaci zemní smyčky a vyzařování.

### 2.2 Odrušení

Pro správnou funkci přijímače je nutné řádné odrušení napájecích zdrojů. Vhodné je také omezit zemní smyčky a zem rozvádět pokud možno hvězdicově. Konstrukce obsahuje několik Jumperů, kterými je možné různými způsoby propojit země a eliminovat tak proudy tekoucí mezi nimi. Zvláště nežádoucí je proměnný proud tekoucí stíněním, například u výstupních CINCHů, Jumpery proto umožňují jejich odpojení od AGND přijímače. V tom případě se ale předpokládá propojení země ADC a AGND externím vedením, tak aby jím tekoucí proud neindukoval signál v analogových obvodech. V některých případech (anténa uzemněna na hromosvod, nebo daleko od přijímače) se může vyskytnout problém se sít’ovým napájeným 50Hz indukovaným do svodu antény. Ten pak vytváří okolo nulové frekvence spektrogramu nežádoucí hrb, ten lze pak v takovém případě eliminovat oddělovacím transformátorem, na vstupu přijímače.
Při provozu je také vhodné zabezpečit dostatečný útlum zpětně vyzařovaného útlumu ze směšovače, který by mohl rušit jiná zařízení a spoje. Na vstupu přijímače proto musí být zařazen izolační prvek, jako například LNA.

### 2.3 Mechanická konstrukce

Mechanická konstrukce je řešena na dvouvrstvé desce s geometrií kompatibilní se základovou deskou MLAB (Pro lepší odstínění přijímače je vhodné použít duralovou desku AL-BASE). Dvouvrstvý plošný spoj je zvolen hlavně kvůli kvalitnímu odstínění okolního rušení horní měděnou vrstvou. To umožňuje přijímače instalovat i velmi blízko sebe případně i nad sebe avšak všechny konektory kromě NF audio výstupu předpokládají přivedení kabelu kolmo na rovinu desky. SMA konektor je možné osadit i úhlový s přivedením kabelu do boku, ale za cenu nepatrně vyššího útlumu úhlového konektoru. Při těsné montáži je potřeba počítat i s určitou teplotní stabilizací, nebot’ digitální část okolo spínaného směšovače má poměrně velký příkon a způsobuje zahřívání zhruba o 15◦C nad okolní teplotu. Pokud je od přijímače vyžadována dlouhodobá stabilita je proto vhodné jej umístit do termostatovaného boxu společně s LO.

## 3 Výroba

Výrobu vlastní desky pro přijímač nemohu doporučit. Nebot’ domácí výroba je dvouvrstvého plošného spoje je náročná sama o sobě a tento motiv plošného spoje navíc obsahuje plošky pro komponenty s poměrně vysokou třídou přesnosti.

### 3.1 Osazení

Vlastní osazení přijímače předpokládá zvládnutí SMT technologie. Nejkomplikovanější část je letování analogových spínačů u kterých je nutné dát pozor na přehřátí a je tedy vhodné použít více tavidla. Následně je potřeba pod mikroskopem zkontrolovat kvalitu pájení (zkraty, nepřipojené nožičky).

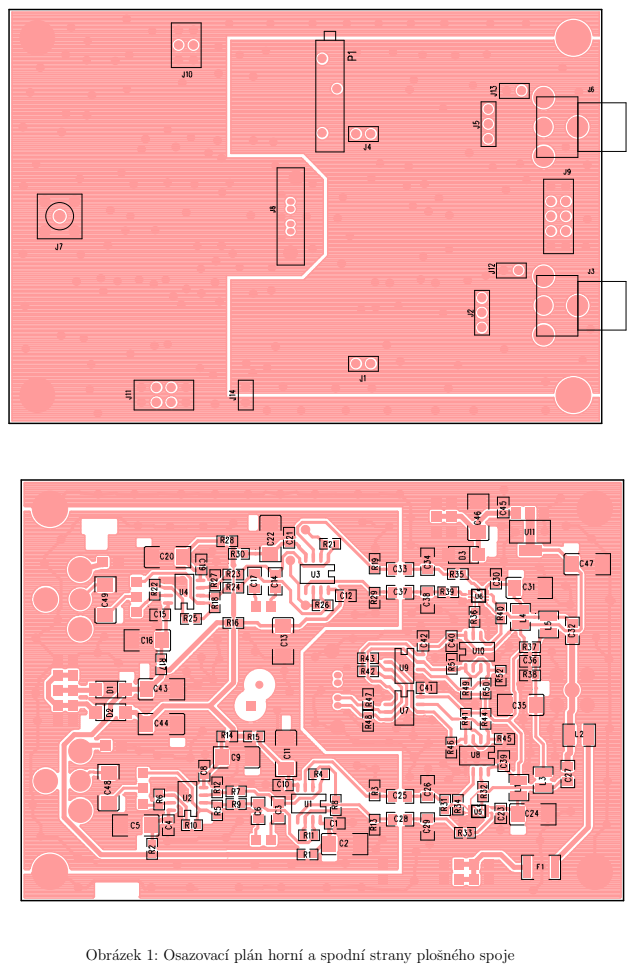
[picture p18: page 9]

Obrázek 1: Osazovací plán horní a spodní strany plošného spoje

Počet | Označení | Typ | Pouzdro
18 | C1, C4, C8, C10, C12, C15, C19, C21, C23, C27, C30, C32, C36, C39, C40, C41, C42, C45 | 100nF | 805
17 | C2, C5, C9, C11, C13, C16,
C20, C22, C24, C31, C35,
C43, C44, C46, C47, C48,
C49
47uF | SMC
4 | C3, C6, C14, C17 | 4,7uF | 805
4 | C25, C28, C33, C37 | 470nF | 805
4 | C26, C29, C34, C38 | 22nF | 805
3 | D1, D2, D3 | M4 | SMA
1 | F1 | 750mA
5 | J1, J4, J12, J13, J14 | JUMP2
2 | J2,J5 | JUMP3
1 | J3 | CINCH I
1 | J6 | CINCH Q
1 | J7 | SMA6251A13G50
1 | J8 | JUMP7
1 | J9 | JUMP2X5
1 | J10 | JUMP2X3
1 | J11 | JUMP2X4
5 | L1, L2, L3, L4, L5 | 100uH
1 | P1 | 200 | 805
13 | R1, R2, R8, R14, R15, R16,
| R17, R28, R30, R32, R34,
| R36, R40 | 100 | 805
12 | R3, R5, R7, R9, R12, R13,
R18, R19, R23, R24, R27,
R29
10k 1% | 805
4 | R4,R11,R21,R26 | 1k 1% | 805
2 | R6,R22 | 47k 1% | 805
2 | R10,R25 | 4k7 1% | 805
10 | R31, R33, R35, R39, R45,
| R46, R47, R48, R51, R52 | 82 | 805
2 | R37,R38 | 330 | 805
6 | R41,R42,R43,R44,R49,R50 | 130 | 805
2 | U1,U3 | LT6231 | SO8
2 | U2,U4 | NE5532 | SO8
2 | U5,U6 | NC7WB66
2 | U7,U9 | MC100EP51 | SO8
2 | U8,U10 | SY100ELT23 | SO8
1 | U11 | LM1117MPX | SOT

Tabulka 2: Seznam součástek plošného spoje.

### 3.2 Testování

Testování přijímače spočívá v připojení na zdroje napájecího napětí s omezením proudu nastaveným na maximální hodnoty uvedené v tabulce 1. Symetrický napájecí zdroj musí být dostatečně kvalitní a vyhlazený, aby nedocházelo k průniku rušení do analogové části. Je taktéž vhodné aby i symetrický zdroj měl proudové omezení. Pokud proudový odběr nepřekračuje stanovené limity. Můžeme připojit i lokální oscilátor. Pro testovací účely stačí použít modul CLKGEN01B pouze s připojeným napájením, tím dosáhneme přivedení jeho základní frekvence 10 MHz na vstupní děličku přijímače.
Nyní můžeme osciloskopem zkontrolovat signál na vstupu analogových spínačů, kde by po připojení oscilátoru přes SATA kabel měl být měřitelný TTL signál. Se střídou 50 % a frekvencí 5 MHz. Je potřeba změřit každý vstup spínače samostatně. Pokud jsou analogové spínače v pořádku, lze pokračovat v ověření parametrů analogové části. To provedeme změřením napět’ového offsetu na výstupním operačním zesilovači. Jeho hodnota by neměla být více než 1 V, měření je vhodné provádět osciloskopem, nebot’ tím lze detekovat i případné kmitání operačních zesilovačů.

### 3.3 Nastavení

Následně je důležité nastavení shodných amplitud obou výstupních kanálů I a Q na stejnou hodnotu pomocí víceotáčkového trimru na horní straně desky. To lze udělat bud’ pomocí zvukové karty a minimalizace zrcadlových kmitočtů nějakého relativně silného AM vysílače. Nebo lze použít i metodu, kdy pomocí Jumperů, které slouží na výběr zesílení odpojíme jeden kanál (ten ve větvi s trimrem) a v softwaru si označíme aktuální úroveň signálu z antény. Pak analogicky kanál odpojíme připojíme naopak původně odpojený. Pomocí trimru pak nastavíme stejnou hodnotu signálu. Tento způsob je velmi jednoduchý a lze ho použít i za chodu, ale není příliš přesný. hodí se spíše na detekci poruchy (nefungující jeden z kanálů).
Nejpřesnější metoda je použití signálového generátoru, který necháme vysílat do přijímače signálem cca -50dBm na požadovaném kmitočtu, kde potřebujeme přijímač zkalibrovat a trimrem nastavíme zrcadlový kmitočet ve spektrogramu na minimální hodnotu. Pokud nemáme signálový generátor lze využít například další přijímač SDRX01B s dalším lokálním oscilátorem. Který díky zpětnému vyzařování do antény umožní stejný postup. Další jeměšjí potlačení zrcadlového kmitočtu lze provádět vhodným nastavením zesílení jednotlivých kanálů ADC a jejich fázovým posuvem. Většina programů pro SDR má proto možnost vyvážení amplitudy a fáze.

## 4 Programové vybavení

Základním programovým vybavením jsou všechny softwary využívající zvukovou kartu v komplexním režimu (I/Q) pro vstup signálu. Tedy například programy jako Winrad, WinradHD, HDSDR či Spectrum Lab. Do kterých většinou stačí přidat knihovnu pro ovládání LO s Si570, nebo lokální oscilátor ovládat jiným softwarem.

## 5 Důležité poznámky k používání

- Vzhledem k použitému principu spínaného směšovače přijímač z principu poměrně silně vyzařuje zpět do antény. Nesmí se proto využívat k poslechu chráněných pásem přímo bez izolačního členu na vstupu! (izolačním členem je myšlen prvek, který zabezpečí dostatečný útlum signálu směřujícího do antény, obvykle jde o LNA, nebo izolační zesilovač)
- Aktuální způsoby použití a poznatky uživatelů přijímače najdete na wiki stránce MLAB [2].

## Reference

[1] Původní konstrukce přijímače DR2G http://yu1lm.qrpradio.com/SMT SDR RX DR2G-YU1LM.pdf
[2] MLAB wiki stránka přijímače SDRX01B http://wiki.mlab.cz/doku.php?id=cs:sdrx

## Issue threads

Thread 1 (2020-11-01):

Remove resistive trimmer

kaklik, 2020-11-01:
The resistive trimmer P1 is an unnecessary component which increases manufacturing costs. It should be replaced by a fixed resistor.

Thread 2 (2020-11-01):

SDRX01C - Use of integrated circuit

kaklik, 2020-11-01:
The SDRX01B receiver contains many components, which result in increased manufacturing costs. The same function could be probably reasonably replaced by some integrated circuit in the next receiver revision.

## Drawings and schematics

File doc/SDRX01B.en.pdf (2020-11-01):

# Software Defined Receiver SDRX01B not only for radioastronomy

### Jakub K´akona, kaklik@mlab.cz

### March 20, 2014

Abstract

This paper describe a design of Software Defined Receiver suitable for radioastronomy purposes. The receiver which has been developed in this project replacing old analog constructions such as RadioJOVE and others.


## Contents

1 Technical parameters | 2
2 Description of construction | 3
3 Software tools | 11

## 1 Technical parameters

Parameter | Value | Note
Power voltage for analog circuits | ±12 V 100mA 1 | Typical current draw 30 mA
Powering voltage for digital part | +5V | 300mA
Bias of optional LNA | up to +20V max 500mA | Fused by 750mA on board
Frequency range | 0,5 - 200 MHz | With populating by chosen parts even up 450MHz
IIP3 | > 0dB | Preliminary
Gain | 40-60dB | Selectable by jumper
Self noise number | < 30dB

1First devices manufactured before 1.8.2011 may be equipped by 10 V tatal capacitors onl thus cannot by longly stressed by ±12 V power voltage

## 2 Description of construction

### 2.1 Circuit

Construction of the receiver is delivered from the DR2G receiver [1] which uses CMOS components completely. The main change in this construction is a local oscillator input circuit which allow to receiver work at higher frequencies, because this construction do not divide the input frequency by 4, such as original construction but only by 2. In addition there was be replaced switches in the sampling mixer by faster type and board layout was optimized for higher frequencies and better noise rejection.





The necessary part of the receiver is a Local Oscillator (LO), which must be connected to receiver via SATA cable. The LO may be a CLKGEN01B module populated by the 570ABB000107DG chip. SATA cable should be as short as possible to minimize ground loops.

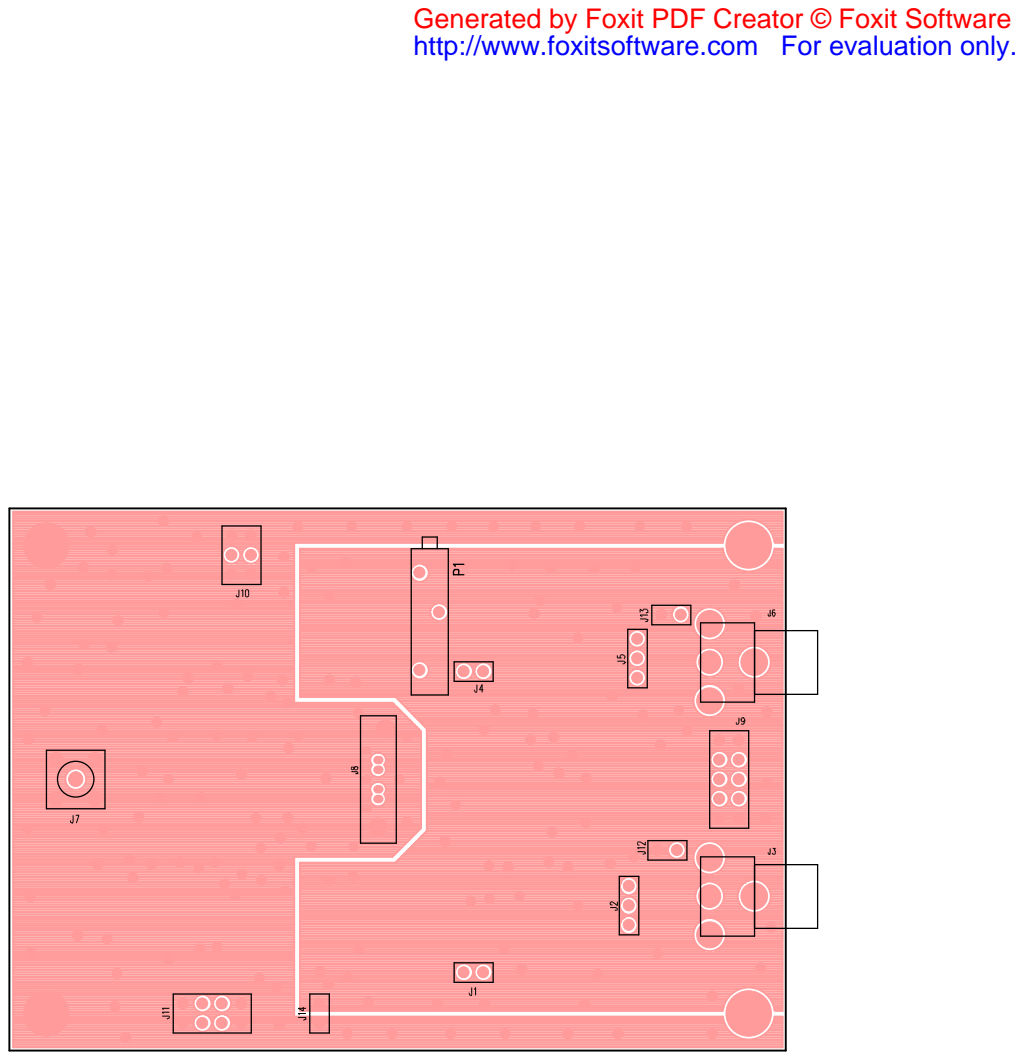
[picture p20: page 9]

Generated by Foxit PDF Creator © Foxit Software
http://www.foxitsoftware.com For evaluation only.

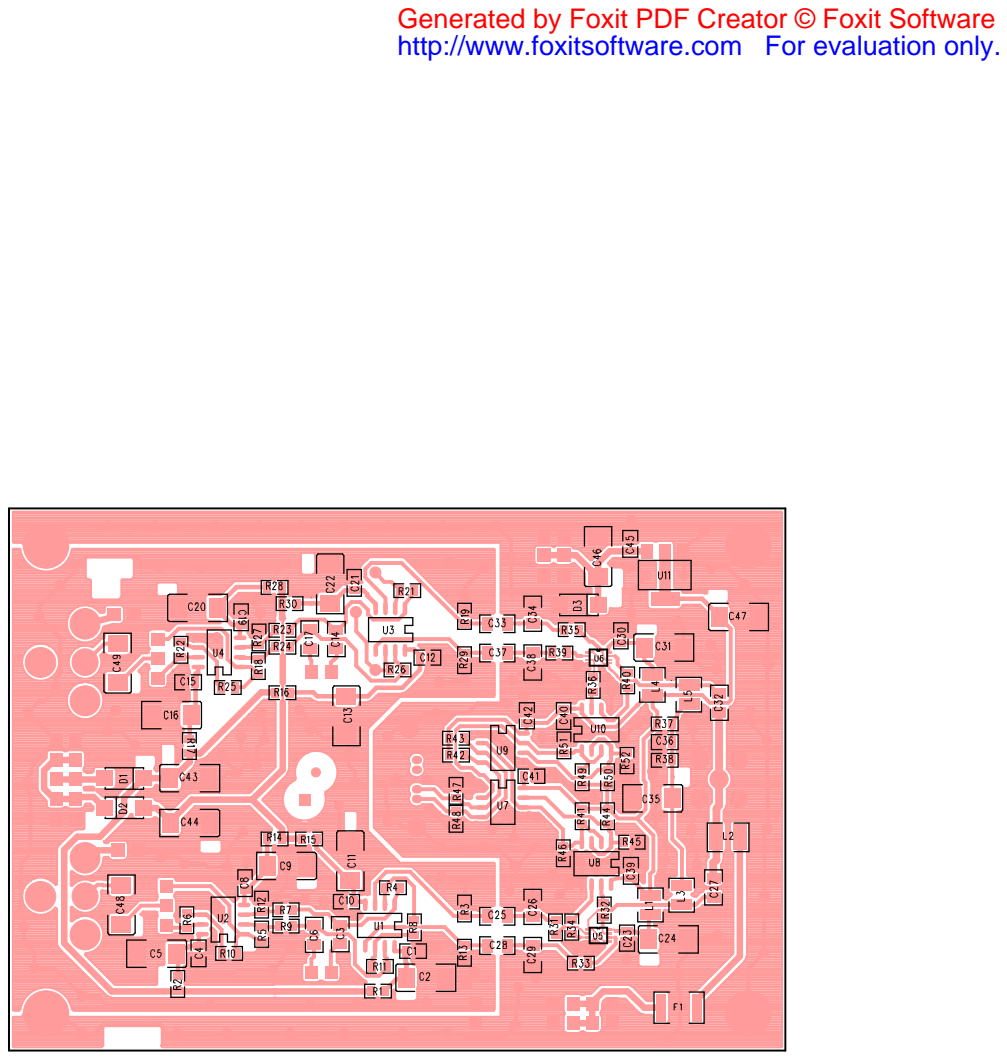
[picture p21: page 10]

Generated by Foxit PDF Creator © Foxit Software
http://www.foxitsoftware.com For evaluation only.

### 2.2 EMI suppression

For proper function of receiver is necessary to use proper low noise symmetric power supply (classical PC power supply is unacceptable). There is need for proper routing of grounding wires, which must be routed in star topology. In addition there is few jumpers on the board of receiver to allow proper selection of ground connection.

### 2.3 Mechanical construction

The mechanical construction of the receiver resulted (For better EMI suppression is sug-gested use of metal MLAB base such as ALBASE). Two layer PCB is chosen mainly because of better shielding by top cooper layer and even because better grounding. In case where long term stability is required receiver must be inserted to thermostatic box together with LO.

### 2.3.1 Setting

There is one easy step for proper setting of the receiver. The trimmer P1 must be tunned to value where the strength of mirror frequencies is minimized or zero. This can be achieved by tunning the receiver to some strength AM transmitter and slowly turning by P1 until the mirror of signal in frequency spectrum is minimized.

## 3 Software tools

The basic software tools for this receiver are all programs designed to work with sound card as I/Q input. Such as Winrad, WinradHD or Spectrum Lab. There is usually request to add a LO library for tunning Si570, but tunning the LO by separate software is acceptable too.

## References

[1] The original construction of DR2G http://yu1lm.qrpradio.com/SMT SDR RX DR2G-YU1LM.pdf

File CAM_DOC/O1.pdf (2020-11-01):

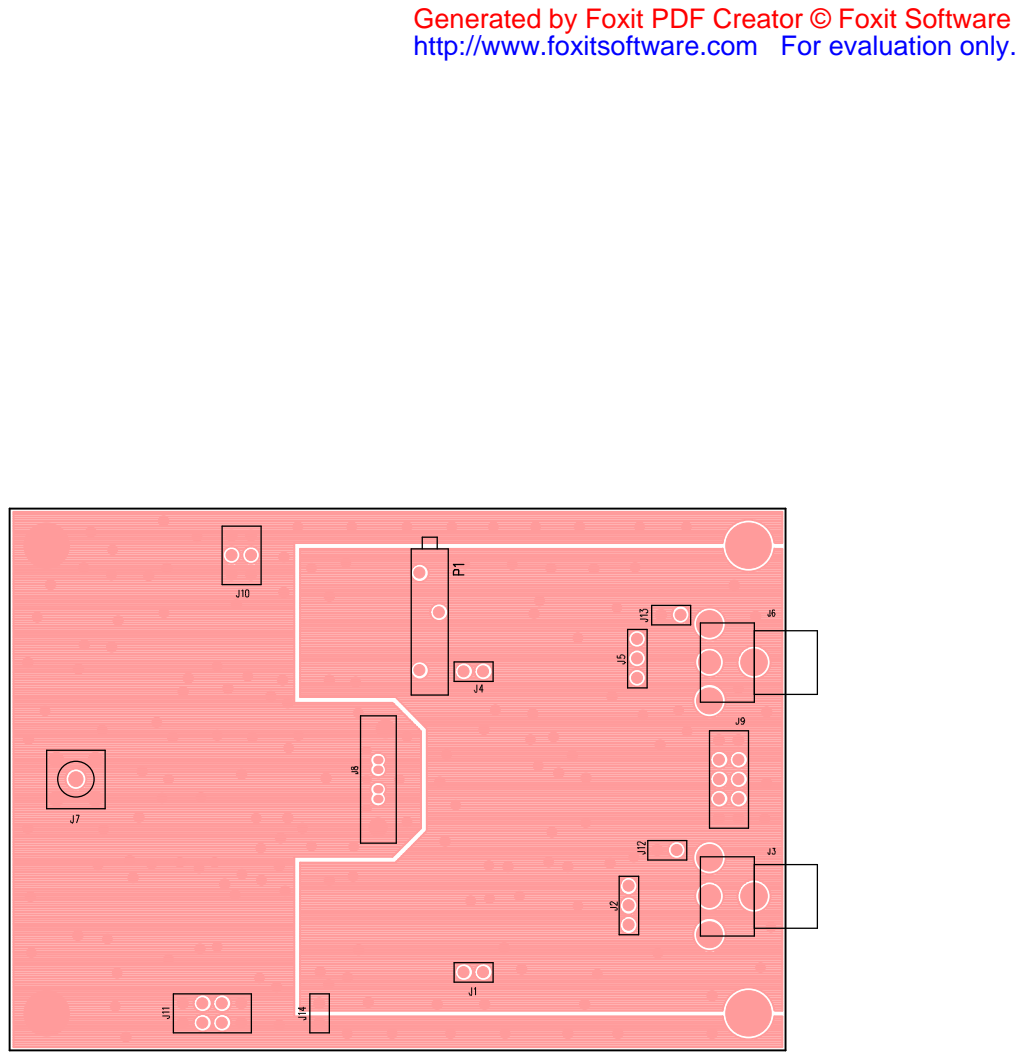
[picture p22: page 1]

Generated by Foxit PDF Creator © Foxit Software
http://www.foxitsoftware.com For evaluation only.

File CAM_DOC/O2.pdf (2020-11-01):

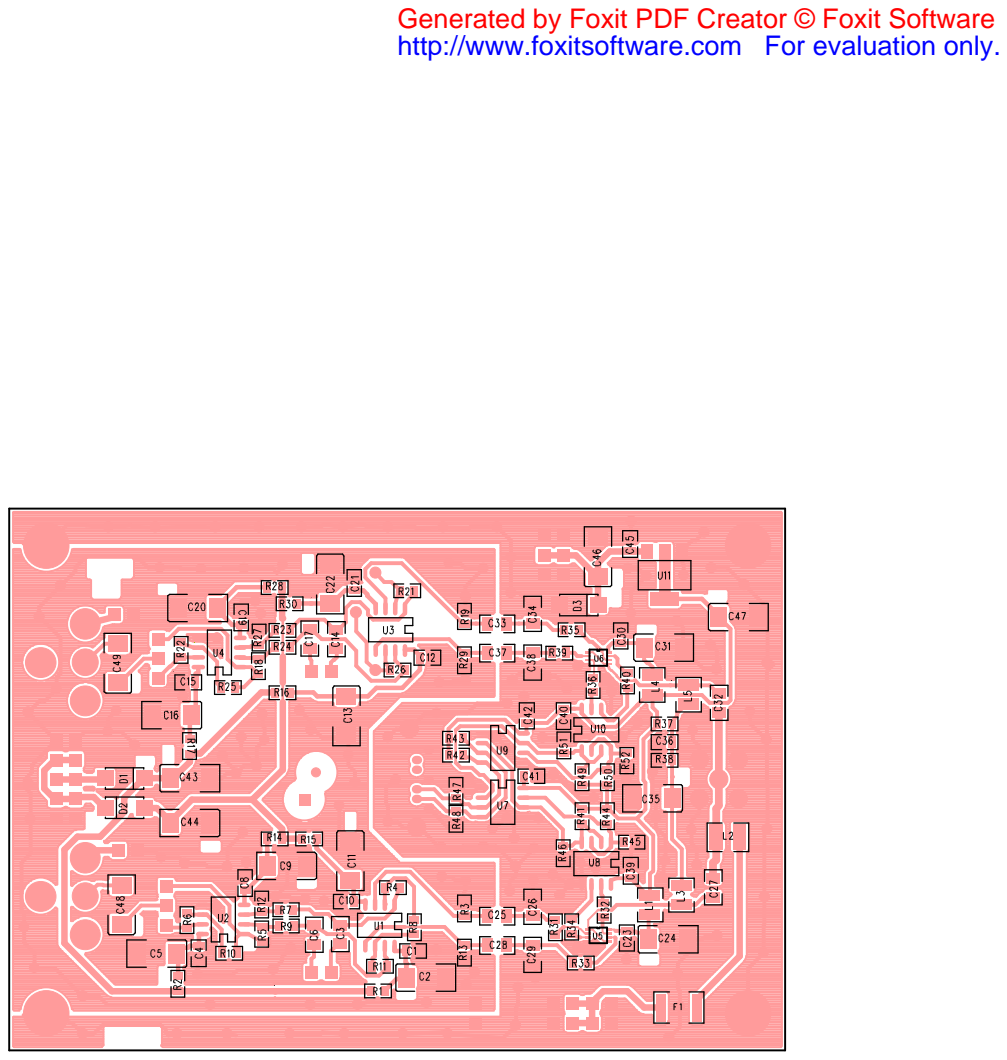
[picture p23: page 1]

Generated by Foxit PDF Creator © Foxit Software
http://www.foxitsoftware.com For evaluation only.

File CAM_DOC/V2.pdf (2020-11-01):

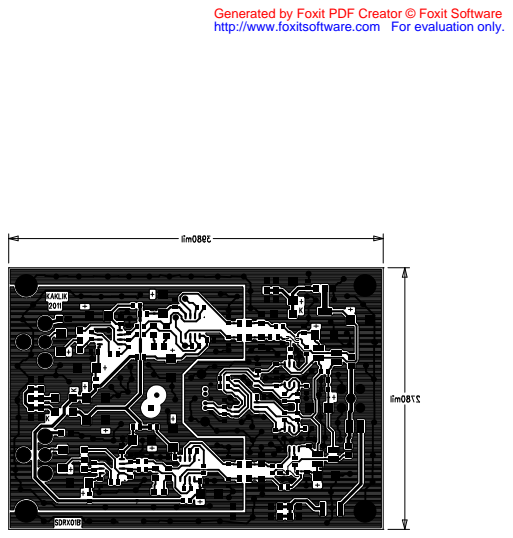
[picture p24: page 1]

Generated by Foxit PDF Creator © Foxit Software
http://www.foxitsoftware.com For evaluation only.

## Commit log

2017-08-24 Renaming top directories.
    [SDRX.DSN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]
2020-11-01 Copy of latest files from SDRX01B SVN repository. (Github import does not work for that svn path)
    [OZDUAL02B.DSN, SDRX.DSN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]
2020-11-01 Repository cleanup
    [OZDUAL02B.DSN, SDRX.DSN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]
2022-04-06 Update actions products
    [DRILL.DRL]
